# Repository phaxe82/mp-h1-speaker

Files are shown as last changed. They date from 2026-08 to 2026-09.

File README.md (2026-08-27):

# MP-H1 — a high-sensitivity 2-way with a 3D-printed tractrix horn

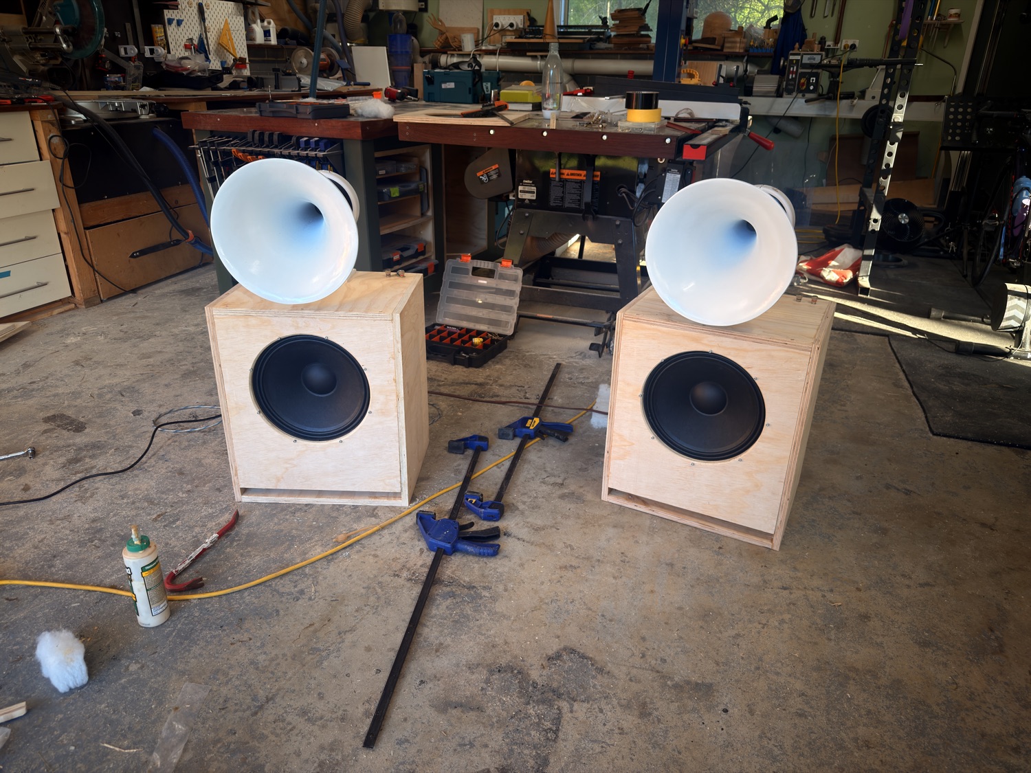
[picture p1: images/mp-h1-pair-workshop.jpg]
The MP-H1 pair, fresh off the bench


An OJAS / Devon Turnbull–inspired two-way: a 12″ pro woofer in a modest reflex
box, and a 1.4″ compression driver on a **3D-printed round tractrix horn** that
sits on top of the cabinet. Both drivers run from a **single amplifier channel**;
the passive crossover is four parts (on the compression driver only) and all the
voicing is done in DSP.

The point of this repo is that it's **designed from the Thiele/Small parameters
up** — the horn profile, the box alignment, and the drawings are all *generated*
by the scripts here. Change the driver, the box volume, or the flare cutoff, and
you can regenerate the whole design.

📄 **Start with the [full build & design paper (PDF)](speaker_docs/MP-H1-Build-and-Design.pdf)** — the maths, the crossover, the tuning method, and the story, in one place.

---

## Specs (as built)

| | |
|---|---|
| **Format** | Two-way, high-efficiency · passive XO (CD only) + DSP voicing · single amp channel |
| **Woofer** | 12″ Peerless by Tymphany **FSL-1225R02-08** — 96.2 dB, reflex |
| **Compression driver** | 1.4″ SB Audience **ROSSO-65CD-T** — 108 dB, titanium |
| **Enclosure** | 62 L net reflex, **f_b ≈ 47 Hz** · 456 × 536 × 366 mm · 18 mm Baltic birch · front slot port |
| **Horn** | Round tractrix, **f_c = 340 Hz** · Ø321 mm mouth · 303 mm long · printed in sections |
| **Crossover** | ≈ 1.2 kHz 2nd-order Butterworth (12 µF + 1.5 mH) · L-pad 6.8 Ω / 2.7 Ω |
| **Extension** | F3 = 67 Hz · F6 = 47 Hz · F10 = 38 Hz — flat into the mid-40s in-room with DSP |
| **Amplification** | Single channel — NAD C 700 + Dirac Live |
| **Cost** | ≈ AU$1,650–1,850 / pair |

## The design, in three ideas

- **Minimal passive parts.** The woofer runs *direct* — no series inductor. Only the compression driver carries a network (a 2nd-order high-pass + a level-matching L-pad).
- **Efficiency first.** 96 dB woofer, 108 dB horn — happy on a handful of watts, so amp quality matters more than power.
- **DSP does the voicing.** Baffle-step, the low-shelf lift, the 40 Hz excursion high-pass and room correction all live in DSP, not the crossover.

## What's in here

```
scripts/        The generators — the reproducible heart of the design
  tractrix.py     horn profile from a flare cutoff frequency
  horn_cad.py     builds the printable horn (neck + bell quadrants), headless build123d
  box_model.py    vented-box (Small) alignment + port model, per driver
  drawings.py     dimensioned cutting drawings (matplotlib → PDF)
cad/            STL (print), STEP (universal CAD), F3D (Fusion), 3MF, drawings.pdf, profile CSVs
speaker_docs/   design-notes.md · BOM.md · build-guide.md · dsp-tuning-guide.md · the build paper (PDF)
website/        the crossover schematic + board-layout page (open index.html)
images/         build photos
```

## Regenerate the design

```bash
python3 -m venv .venv
.venv/bin/pip install build123d numpy scipy matplotlib

.venv/bin/python scripts/box_model.py                     # box alignment + port, prints the response
.venv/bin/python scripts/tractrix.py 340 cad/horn_profile_340.csv   # horn profile CSV
.venv/bin/python scripts/horn_cad.py                      # → cad/horn_neck.stl + horn_bell_quadrant.stl (+ .step)
.venv/bin/python scripts/drawings.py                      # → cad/drawings.pdf
```

Want a different horn? Change the flare cutoff (`tractrix.py <fc>`); a different
woofer or box? Edit the T/S set / volume in `box_model.py` and re-check the
alignment before you cut anything.

## Print the horn

Per speaker: **1 × `horn_neck.stl` + 4 × `horn_bell_quadrant.stl` + 1 × `driver_stand.stl`**.

- **PETG**, 0.2 mm layers, **6 mm walls** (≈ 8 perimeters or 30 %+ gyroid). The horn must be *dead* — a knuckle-rap should give a dull thock, not a ring.
- The bell quadrants are one identical part rotated 90° four times, with **integral tongue-and-groove** on every seam — dry-fit, epoxy in the grooves, tape, cure. No hardware.
- The **driver stand is structural** (it carries the 3.76 kg driver) — 50 %+ infill, 6 perimeters.

Full sequence, finishing, and the wiring in **[speaker_docs/build-guide.md](speaker_docs/build-guide.md)**.

## Build & tune

1. Order parts — **[speaker_docs/BOM.md](speaker_docs/BOM.md)**
2. Start the horn prints (longest lead time)
3. Build the cabinets — **[speaker_docs/build-guide.md](speaker_docs/build-guide.md)** + the drawings in `cad/`
4. Wire the crossover (**[website/index.html](website/index.html)** has the schematic + board layout), assemble, then measure and voice — **[speaker_docs/dsp-tuning-guide.md](speaker_docs/dsp-tuning-guide.md)**

> **One hard-won tip:** before you second-guess the acoustics on first power-up, **battery-test your woofer polarity**. A single reversed woofer makes a stereo pair sound thin and lifeless — the two cancel in the room. Ask me how I know.

## Licence

- **Hardware, CAD, and docs** → [CC BY-SA 4.0](LICENSE) (share & adapt, keep derivatives open, credit the source)
- **Scripts** (`scripts/`) → [MIT](LICENSE-CODE)

Build it, remix it, improve it — please do. If you make a better horn, open a PR.

---

*Designed and built by Tom Andrews on the Mornington Peninsula, Australia.
Round tractrix, single-amp, high-sensitivity two-way. Next revision: **MP-H2**,
an elliptical R-OSSE waveguide swap-in.*

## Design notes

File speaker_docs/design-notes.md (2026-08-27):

# Design Notes — MP-H1 (OJAS-Style 2-Way Horn Speaker)

**MP-H1** — Mornington Peninsula, Horn, rev 1: round-tractrix, single-amp,
high-sensitivity 2-way. (MP-H2 reserved for the elliptical R-OSSE waveguide swap.)

All the acoustic math behind the build, with sources. Scripts that produced
these numbers: `scripts/box_model.py`, `scripts/tractrix.py`.

## 1. Concept

Two-way, high-efficiency: 12" reflex bass bin + compression driver on a
3D-printed round tractrix horn sitting on top. Modeled on the OJAS (Devon
Turnbull) two-way — the real kit uses a FaitalPRO 15PR400 + HF10AK on a long
tractrix; the Klipsch×OJAS kO-R2 crosses at 760 Hz with 97 dB sensitivity.
Drivers here are Celestion for Australian availability.

Amplification: 2-channel amp with DSP. So: **woofer runs direct** (no series
parts), **compression driver gets a passive 2nd-order high-pass + L-pad**,
and all voicing is DSP PEQ. This mirrors OJAS practice (minimal passive
parts, high-efficiency drivers, low amplifier power).

## 2. Drivers (datasheet values)

> **Revision 2 (July 2026):** design re-based on Wagner Online stock —
> Celestion proved unobtainable in Australia (TF1225 out of stock at the
> stockists checked; CDX14-3050 $499 at the one that had it). Both
> replacement drivers below are stocked by
> [Wagner Online](https://www.wagneronline.com.au) (Australian
> SB Audience / Peerless / Dayton distributor). Original Celestion figures
> remain in `box_model.py` for reference.

### Woofer — Peerless by Tymphany FSL-1225R02-08 (8 Ω), chosen
| Fs | Qts | Qes | Vas | Re | BL | Sd | Xmax | Mms | Le | Sens | Power |
|---|---|---|---|---|---|---|---|---|---|---|---|
| 63.0 Hz | 0.44 | 0.49 | 54.8 L | 5.5 Ω | 14.9 Tm | 547 cm² | 5.3 mm | 50.1 g | 0.54 mH | 96.2 dB | 233 W AES |

Pro-style pressed-steel 12", paper cone, 65 mm voice coil, spec'd by
Tymphany as "extremely flat response up to 3,000 Hz" — the same recipe as
the TF1225 it replaces, with more Xmax. Frame Ø313.5 mm, depth ~96 mm
(shallower than the TF1225's 130 mm — more brace clearance). **Baffle
cut-out: nominal Ø285 mm — verify against the delivered driver before
routing** (the cutout/bolt-PCD page of the datasheet isn't in any public
mirror; 12" pro frames land 283–287 mm).

*(Earlier candidates: Celestion TF1225 — unobtainable in AU;
FTR12-3070C — rejected, higher Fs / smaller Vas = less extension.)*

### Compression driver — SB Audience ROSSO-65CD-T (8 Ω)
- **108 dB** 1W/1m, 70 W AES (140 W max), RDC 6.2 Ω
- Frequency range 500–20,000 Hz; **recommended crossover 1 kHz**
- Throat exit **35.6 mm (1.4")**, fitting **4 × M6 at 90° on Ø102 mm PCD** —
  identical to the Celestion CDX14-3050 it replaces, so **the printed horn
  flange in `cad/` fits unchanged** (36.0 mm bore vs 35.6 mm exit is a
  0.2 mm/side step; give the throat entry a light chamfer when finishing)
- 65 mm titanium diaphragm, ferrite motor, annular phase plug, copper-cap
  demodulation, 18.4° conical exit angle
- Body **Ø156 mm, depth 65.9 mm, 3.76 kg** — bigger and heavier than the
  Celestion (Ø125 mm / 1.7 kg): driver stand resized accordingly
  (Ø157 mm clamp ring, 50×50 column, 110×110×10 base)

## 3. Bass bin alignment (box_model.py)

Model: Small's 4th-order vented transfer function, QL = 7. Code sanity-checked
against the textbook B4 alignment (reproduces −3.01 dB at f0 with
Qts = 0.383, α = 1.414).

**Chosen: Vb = 62 L net (the as-modeled cabinet), fb = 48 Hz**
(FSL-1225R02-08: α = 0.88, h = 0.76). The cabinet was designed around the
TF1225 at the same tuning, and the FSL-1225 lands in the same place — with
the unchanged 150 mm duct the actual tuning computes to ~47 Hz. **No cabinet
or port change was needed for the driver swap.**

| f (Hz) | 40 | 45 | 50 | 55 | 60 | 70 | 80 | 100 | 150 | 200 |
|---|---|---|---|---|---|---|---|---|---|---|
| dB | −9.0 | −6.7 | −5.3 | −4.4 | −3.7 | −2.7 | −2.0 | −1.2 | −0.4 | −0.2 |

F3 = 67 Hz, F6 = 47 Hz, F10 = 38 Hz — essentially identical extension to the
original Celestion alignment. The rolloff is intentionally shallow (QB3-ish
pro-driver alignment): a gentle DSP low-shelf (+3–4 dB below ~100 Hz) plus
normal room gain gives flat in-room response into the mid-40s.

**Excursion:** ~2.5 mm peak at 30 W across 48–200 Hz vs Xmax 5.3 mm — fine.
Below fb the cone unloads, so **set a DSP high-pass at 40 Hz (24 dB/oct)**,
especially if using the low-shelf boost.

**Port:** full-width slot at the bottom of the front baffle (as in the
reference photo), formed by a shelf above the cabinet floor:
- Slot: **420 mm wide × 28 mm high** (Sp = 117.6 cm²)
- Physical duct length (front-to-back): **150 mm** (end correction 0.85·d_eq)
- Port velocity at fb, 30 W: ≈ 16.5 m/s peak — under the ~17 m/s chuffing
  threshold at realistically loud levels (30 W on 97 dB = ~112 dB peaks).

**Cabinet internal:** 420 W × 500 H × 330 D mm = 69.3 L gross.
Deductions: driver ≈ 3 L, port duct air 1.8 L, port shelf wood 1.1 L,
bracing ≈ 1 L → **net ≈ 62 L** (within 5% of target; tuning shifts <1 Hz).
External with 18 mm Baltic birch: **456 W × 536 H × 366 D mm**
(H/W = 1.18, matching the photo's proportions).

## 4. Horn (tractrix.py)

Tractrix with mouth radius r_m = c/(2π·fc); profile closed form
x(r) = r_m·ln((r_m + √(r_m²−r²))/r) − √(r_m²−r²).

**Chosen: fc = 340 Hz** → mouth **Ø321 mm**, axial length **303 mm** from
36 mm throat. Loading is effective from ~450 Hz, i.e. > 1.5 octaves below
the 1.15 kHz crossover — generous margin. (fc = 400 Hz / Ø273 was computed
as the smaller alternative; 340 Hz matches the photo scale and loads lower.)
Profile CSV for CAD: `cad/horn_profile_340.csv`.

**Print sectioning (235 × 235 × 250 mm bed) — as modeled in `cad/`:**
- **Neck** (throat → split at x = 230 mm): one vertical piece,
  167.5 × 167.5 × 238 mm, integrated CDX14/ROSSO bolt flange (Ø130 × 8 mm,
  4 × M6 on Ø102 PCD, Ø6.5 clearance holes).
- **Bell** (x 230–303 mm): 4 identical quadrants, 168.6 × 166.6 × 72.6 mm each.
- Wall 6 mm throughout.

> **Rev 3 (Aug 2026): screwless joints.** The rev-2 print run showed the bell
> quadrants fitting poorly — the only registration feature was 8 × Ø4×20mm
> pin sockets across the *neck-to-bell* split; the four quadrant-to-quadrant
> seams (where the visible misalignment actually was) had no registration at
> all, just a butt joint held square by hand while the epoxy set. Replaced
> the pins with **integral tongue-and-groove joints printed directly into
> the parts, on every split**: a continuous ring at the neck-bell interface,
> plus 3 tabs per quadrant-to-quadrant seam (tongue on one radial face,
> groove on the other — all 4 quadrants stay a single identical STL, since
> a part with tongue on its "trailing" face and groove on its "leading"
> face self-tiles into a ring under 90° rotation). No hardware, no drilling;
> assembly is dry-fit → epoxy in the grooves → tape/clamp → cure. Joint
> clearance is 0.15mm/side (width) and 0.2mm (depth) — tune in
> `scripts/horn_cad.py` (`GROOVE_CLEAR_W`/`GROOVE_CLEAR_D`) if your printer
> runs tighter or looser than that.
>
> **`scripts/horn_cad.py` (build123d, headless) is now the source of truth
> for `cad/horn_neck.stl` and `cad/horn_bell_quadrant.stl`** — regenerate
> with `.venv/bin/python scripts/horn_cad.py` after any profile/joint
> change. `speaker-full-design.f3d` still owns the cabinet and driver
> stand; it was not updated for this revision and is stale for the horn
> specifically.

## 5. Crossover / electrical

Both drivers hang on one amp channel. Woofer direct. CD chain:
**2nd-order Butterworth high-pass → L-pad → driver.**

- Target corner ≈ **1.2 kHz** acoustic (ROSSO recommended min is 1.0 kHz; the
  horn's own rolloff below ~450 Hz adds protection).
- Into 8 Ω: **C = 12 µF** (series, film/MKP 250 V) and **L = 1.5 mH**
  (shunt, air core, ≥0.7 mm wire). fc = 1/(2π√(LC)) = 1.19 kHz, Q ≈ 0.72. ✓
- **L-pad −12 dB** (ROSSO 108 → woofer 96.2 dB): series **6.2 Ω**, shunt
  **2.7 Ω** (10 W wirewound each; gives −12.2 dB into ~8.2 Ω). Keeps ~8 Ω
  load and damps horn impedance peaks. Alternates: −10.5 dB = 5.6 Ω/3.3 Ω;
  −13.5 dB = 6.8 Ω/2.2 Ω. Final trim by ear / REW after measuring actual
  sensitivity on *this* horn (spec sensitivity is on SB's H280 horn, ±~2 dB
  on ours).
- System impedance minimum ≈ 4.4 Ω near crossover (woofer ~9.6 Ω at 1.5 kHz
  in parallel with padded network) — safe for any 4 Ω-rated amp channel.
- DSP does the rest: 40 Hz HP, low-shelf, baffle-step/room EQ, and any
  top-octave lift (above ~5 kHz global EQ only affects the horn anyway).

## 6. References

- SB Audience ROSSO-65CD-T spec + dimension sheets (sbaudience.com)
- Peerless FSL-1225R02-08 T/S set (loudspeakerdatabase.com; Tymphany product page)
- Celestion TF1225 / CDX14-3050 / FTR12-3070C datasheets (rev-1 design, for reference)
- Small, R. "Vented-Box Loudspeaker Systems" JAES 1973 (transfer function)
- Klipsch × OJAS kO-R2 product page (reference: 760 Hz crossover, 97 dB)
- OJAS 2-way DIY kit (FaitalPRO 15PR400 + HF10AK, long tractrix)

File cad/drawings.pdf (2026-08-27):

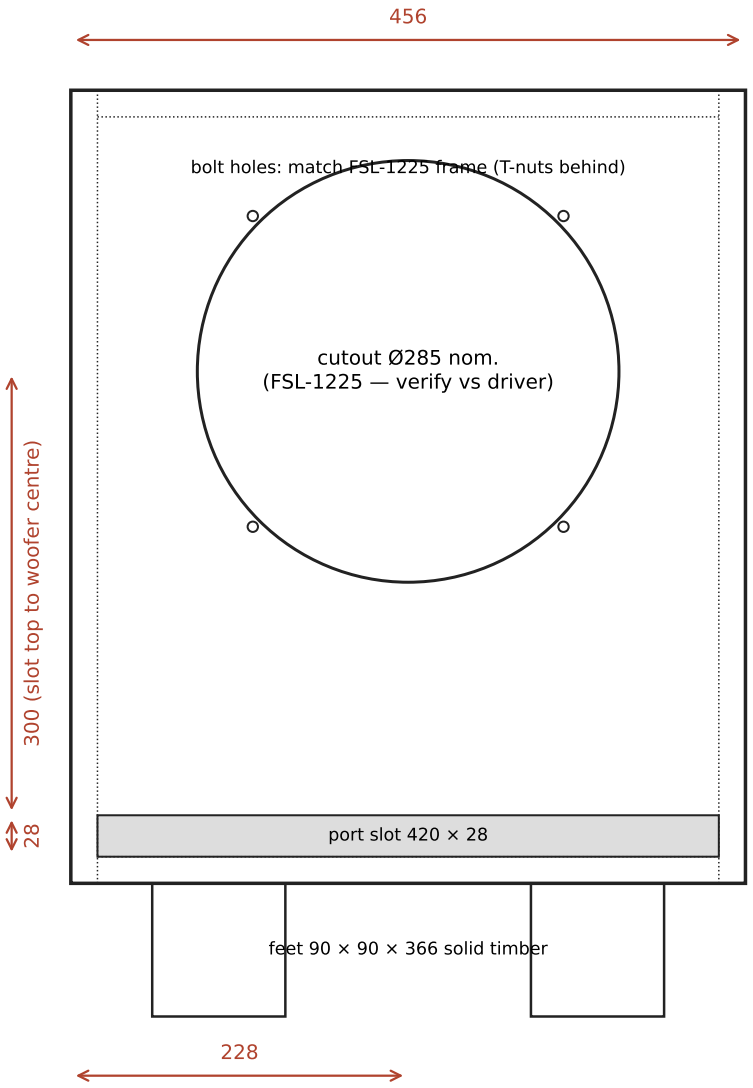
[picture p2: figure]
port slot 420 × 28; cutout Ø285 nom. (FSL-1225 — verify vs driver); feet 90 × 90 × 366 solid timber; 28 300 (slot top to woofer centre)

bolt holes: match FSL-1225 frame (T-nuts behind)

536

## Sheet 1 — Cabinet front elevation (mm)

port shelf

window brace 420×330, 300×210 cutout

duct 150 deep × 28 high

FSL-1225
depth ~96

terminal Ø60 @ z=100

CD cable exit Ø10 @ y=183

366

536

28 duct

132 shelf

## Sheet 2 — Vertical section, side view (mm)

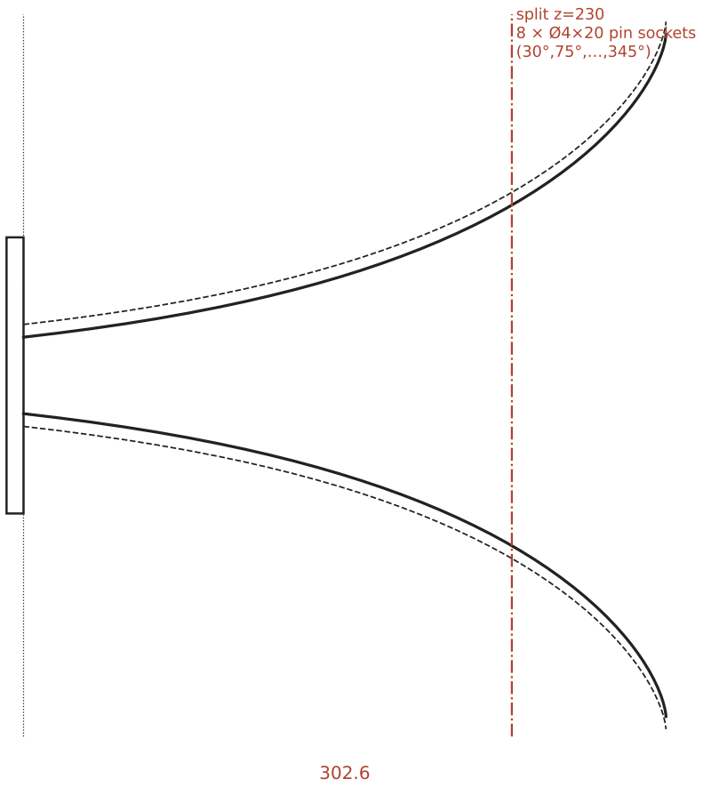
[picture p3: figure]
split z=230 8 × Ø4×20 pin sockets (30°,75°,…,345°)

flange Ø130×8
4×M6 on Ø102 PCD
(ROSSO-65CD-T)

Ø321 mouth
Ø36 throat

wall 6 mm · neck prints vertical (174×174×238) · bell = 4 identical quadrants (161×161×73)

## Sheet 3 — Horn section, tractrix fc = 340 Hz (mm)

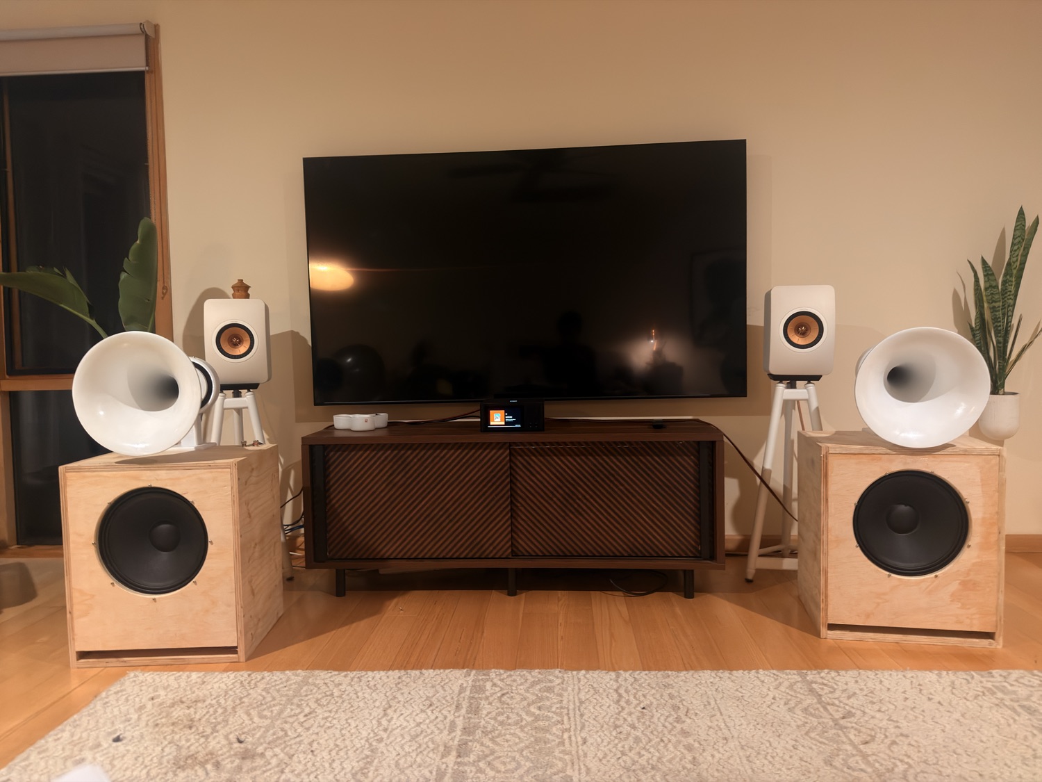
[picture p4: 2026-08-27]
images/mp-h1-pair-inroom.jpg

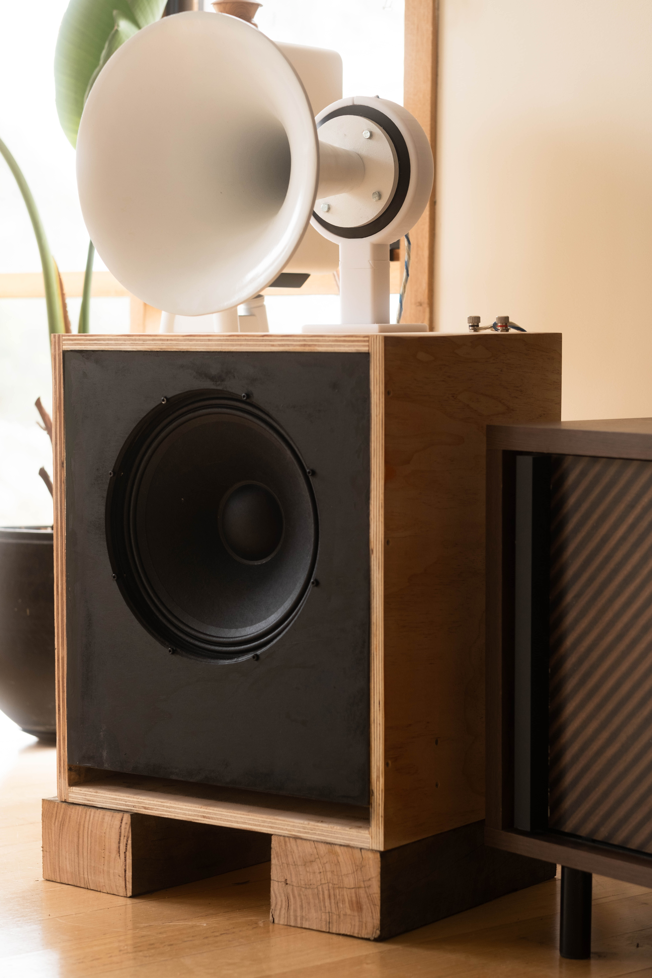
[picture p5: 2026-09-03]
images/untitled-89.jpg

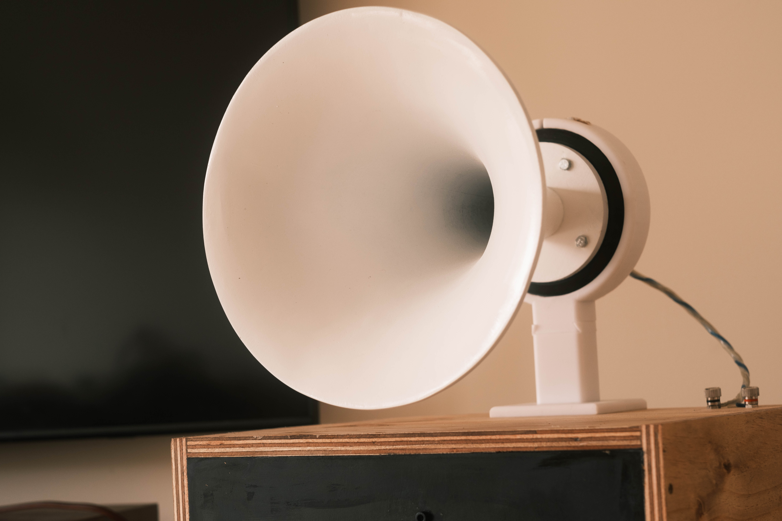
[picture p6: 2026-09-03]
images/untitled-86.jpg

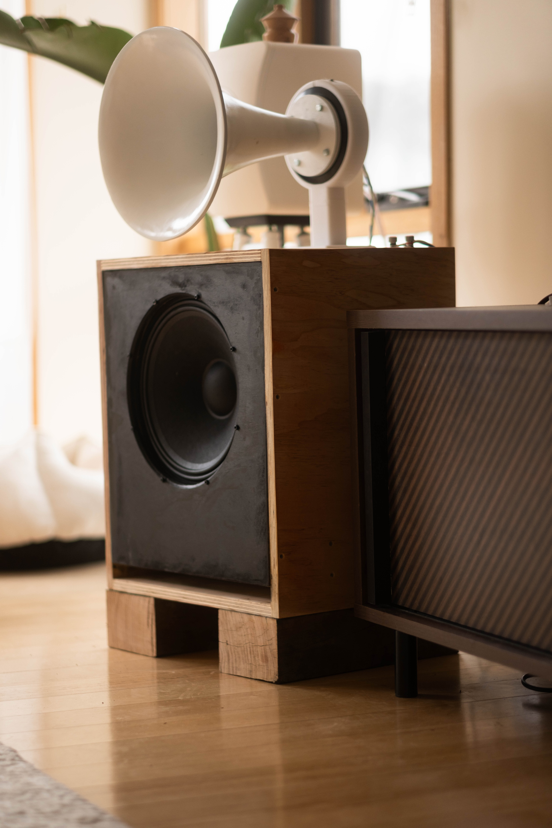
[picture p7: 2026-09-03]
images/untitled-114.jpg

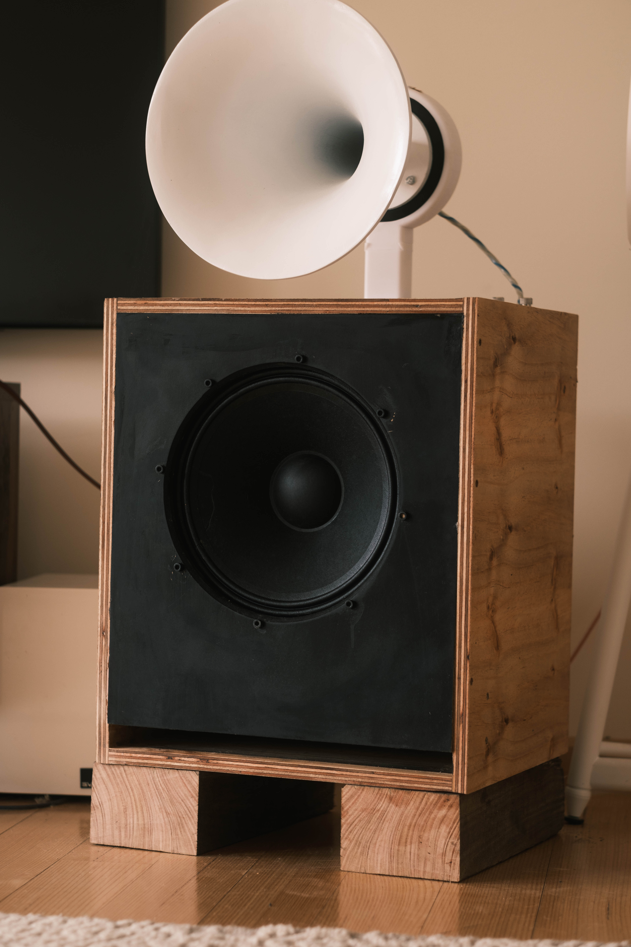
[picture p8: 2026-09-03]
images/untitled-95.jpg

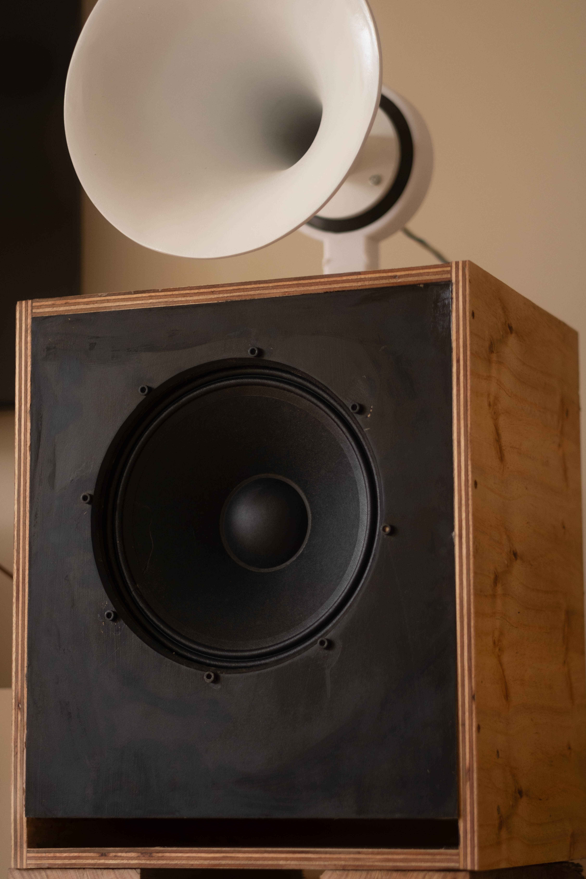
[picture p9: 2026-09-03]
images/untitled-107.jpg

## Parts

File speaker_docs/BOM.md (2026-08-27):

# Bill of Materials — MP-H1 (OJAS-Style 2-Way, pair)

Prices checked July 2026; confirm stock at order time — small-run pro-audio
stock moves fast.

## Drivers — Wagner Online (rev 2, July 2026)

Both confirmed listed at [Wagner Online](https://www.wagneronline.com.au)
(Sydney; AU distributor for SB Audience / Peerless / Dayton). Wagner's site
blocks price scraping — check the product page or call (02) 9798 9233 for
current pricing; estimates below are from US street prices + typical AU markup.

| Qty | Item | Source | Est. AUD | Stock (checked) |
|---|---|---|---|---|
| 2 | Peerless by Tymphany FSL-1225R02-08 12" pro woofer, 8 Ω | [Wagner product page](https://www.wagneronline.com.au/product/peerless-by-tymphany-12-woofer-driver-994241?sku=fsl-1225) | ~$150–190 ea (US$74 at DigiKey) | Listed; Parts-Express has it on clearance — if Wagner is out, order 2 spares-worth while it lasts |
| 2 | SB Audience ROSSO-65CD-T 1.4" compression driver, 8 Ω | [Wagner product page](https://www.wagneronline.com.au/product/sb-audience-1-4-compression-driver-1005231?sku=rosso-65cd-t) | ~$260–320 ea (US$156 at Madisound) | **In stock** per Wagner listing |

Driver subtotal ≈ **$850–1,000** — back inside the original budget tier.

**Superseded (rev 1):** Celestion TF1225 + CDX14-3050 — TF1225 out of stock
at every AU stockist checked; CDX14-3050 $499 ea at the single stockist
(Crossfader). The Celestion pair remains a valid drop-in if stock returns:
same cabinet, same horn flange; use the rev-1 L-pad values in git history.

## Crossover (per speaker: C + L + 2 resistors)

| Qty | Item | Notes | Est. AUD |
|---|---|---|---|
| 2 | 12 µF MKP film capacitor, ≥400 V | **as built: PB-MKP-FC 12 µF 400 V**. Jantzen Cross-Cap / Dayton PMPC also fine (≥250 V); 10 µF + 2.2 µF parallel works too | ~$15 ea |
| 2 | 1.5 mH air-core inductor, ≥0.9 mm (20 AWG) wire | Jantzen air core; DCR ≤0.6 Ω | ~$25 ea |
| 2 | 6.8 Ω 10 W wirewound resistor | **L-pad series, as built** (6.8 Ω = −12.8 dB; 6.2 Ω nominal was −12.2 dB). Buy 5.6 Ω and 8.2 Ω too for ±1.5 dB trim (cheap) — see below | ~$4 ea |
| 2 | 2.7 Ω 5 W wirewound resistor | **L-pad shunt, as built** (5 W is fine — the shunt leg dissipates ~¼ of the series leg; 3.3 Ω / 2.2 Ω alternates) | ~$3 ea |

Mount parts on a small ply board on the cabinet floor. Subtotal ≈ **$100**

## Timber & cabinet hardware

| Qty | Item | Notes | Est. AUD |
|---|---|---|---|
| 2 sheets | 18 mm Baltic birch plywood, 2400×1200 | ~1.3 sheets needed; spare covers mistakes. AA/BB grade for exposed edges | ~$140 ea |
| 1 | Solid timber for feet, ~90×90 mm section, 1.6 m (e.g. Vic ash / oak) | 4 blocks per photo style | ~$60 |
| 8 | Binding posts (4 per speaker) | rear pair = amp input, top pair = external-horn feed through the lid (bed in sealant) | ~$4 ea |
| 4 | Wago 221 lever-nuts | join the negative rail (amp / woofer / crossover-in) — 2 per speaker | ~$2 ea |
| 8 | M6 T-nuts + M6×35 hex bolts (woofer) | 4 per woofer | ~$15 |
| 8 | M6×25 bolts + washers (CD to horn flange) | 4 per driver | ~$8 |
| 2 m² | Polyester/wool acoustic wadding | line rear + side walls | ~$25 |
| — | Foam gasket tape, wood glue, screws | | ~$25 |
| 4 m | Internal cable 1.5 mm² + spade terminals for CD | | ~$15 |

Subtotal ≈ **$440**

## Horn & finish

| Qty | Item | Notes | Est. AUD |
|---|---|---|---|
| ~5 kg | PETG or PLA+ filament | ~2–2.5 kg per horn incl. supports/stand; PETG preferred (sanding + heat resistance) | ~$150 |
| 2 | M5 × 30 bolt + nyloc nut (stand clamp) + 8 × 4 mm wood screws (stand base) | stand is fully printed | ~$8 |
| — | 4 mm rod or filament offcuts for horn joint pins (16 × 20 mm pins) | | ~$0 |
| — | Body filler / spot putty, sandpaper 120–600 | seam finishing | ~$40 |
| — | High-build primer + white satin/gloss acrylic spray | the seamless white look | ~$50 |

Subtotal ≈ **$255**

## Measurement (if not already owned)

| Qty | Item | Notes | Est. AUD |
|---|---|---|---|
| 1 | miniDSP UMIK-1 USB measurement mic | for REW; used for DSP tuning | ~$150 |

## Total ≈ **$1,650–1,850** for the pair (excl. mic)

Rev-2 drivers (~$850–1,000 via Wagner) bring the build back inside the
original ~$800–1000 driver tier. Wagner also stocks the crossover parts
(Jantzen/Dayton caps & coils, resistors) and speaker terminals — most of
this BOM can ship in one box; plywood and timber are the only local buys.

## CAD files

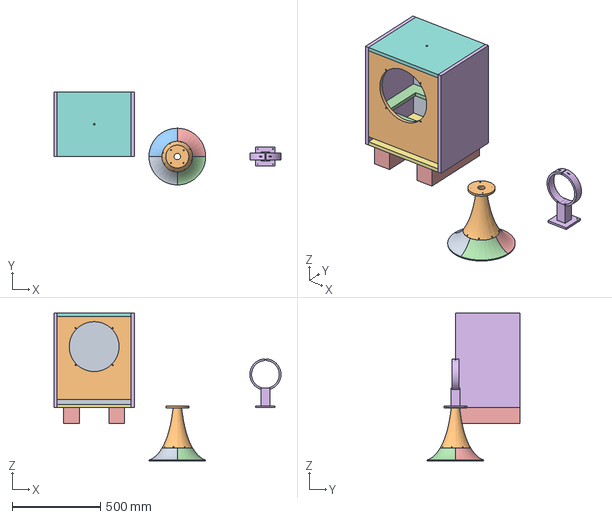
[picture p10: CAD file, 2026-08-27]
cad/speaker-full-design.step
1288.4 x 527.0 x 838.6 mm

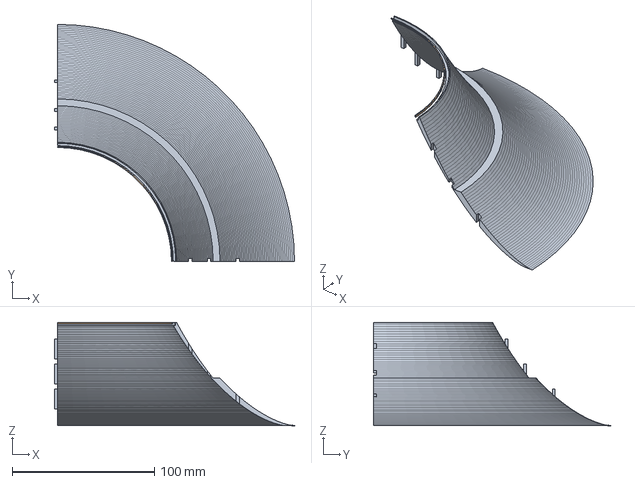
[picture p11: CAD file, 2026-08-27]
cad/horn_bell_quadrant.step
168.6 x 166.6 x 72.6 mm

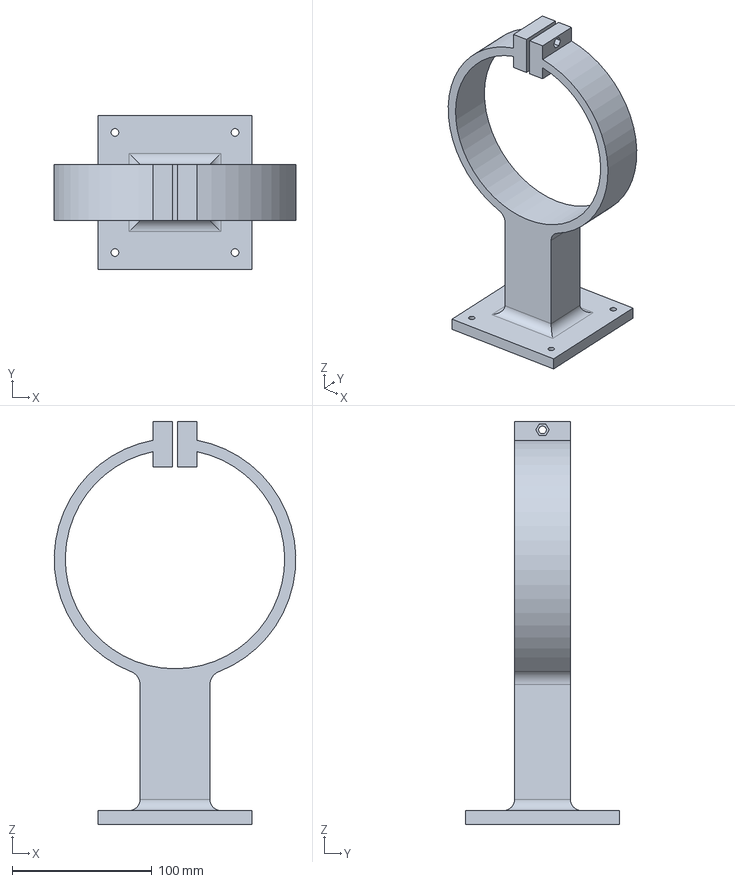
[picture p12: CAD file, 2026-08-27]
cad/driver_stand.step
172.9 x 110.0 x 288.5 mm

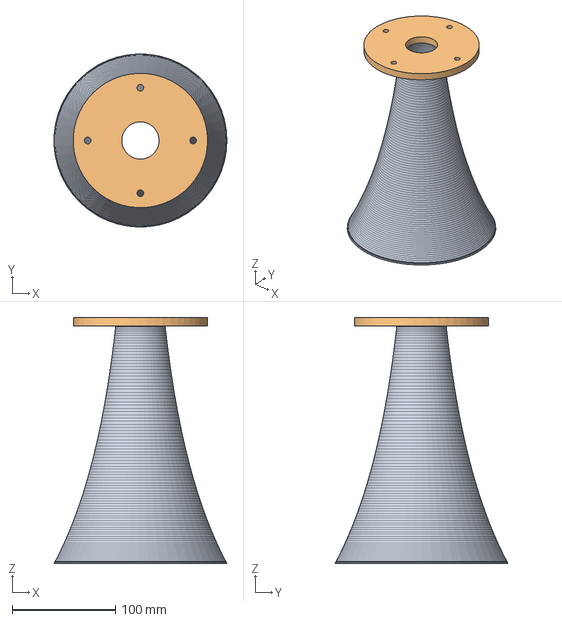
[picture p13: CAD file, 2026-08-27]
cad/horn_neck.step
167.3 x 167.4 x 238.0 mm

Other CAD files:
cad/driver_stand.stl
cad/horn_bell_quadrant.3mf
cad/horn_bell_quadrant.stl
cad/horn_neck.3mf
cad/horn_neck.stl
cad/speaker-full-design.f3d

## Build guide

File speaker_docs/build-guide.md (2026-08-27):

# Build Guide — OJAS-Style 2-Way

Read `design-notes.md` first for the why; this is the how. Dimensioned
drawings and cut list live in `cad/`.

## 1. Cabinet (per speaker) — 18 mm Baltic birch

External 456 W × 536 H × 366 D mm. Butt joints, glued and screwed (screws
hidden on bottom/back or plugged); the photo look leaves ply edges exposed
on the sides, with the front baffle set flush between them.

### Cut list (per cabinet, 18 mm ply)
| Panel | Size (mm) | Qty | Notes |
|---|---|---|---|
| Sides | 536 × 366 | 2 | edges exposed front + top |
| Top / Bottom | 420 × 366 | 2 | fit between sides |
| Back | 420 × 500 | 1 | fits between sides, top, bottom |
| Front baffle | 420 × 472 | 1 | stops 28 mm above the bottom panel → the port slot |
| Port shelf | 420 × 132 | 1 | butts against baffle rear, 28 mm above bottom; with the baffle it forms the 150 mm duct |
| Window brace | 420 × 330 (cut ~60% out) | 1 | mid-height, ties sides/back |
| Crossover board | ~150 × 200 | 1 | screwed to floor after wiring |

*(Exact sizes and the woofer cutout position come from the CAD drawings —
`cad/` is authoritative if anything differs.)*

### Assembly order
1. Cut all panels; cut the woofer hole (nominal Ø285 mm for the FSL-1225 —
   **verify against the delivered driver**) in the baffle with a router
   trammel. Woofer centre is on the vertical centreline, 300 mm up from the
   baffle's bottom edge (i.e. above mid-height, per the photo).
2. Mark the woofer mounting holes from the driver frame itself and fit M6
   T-nuts from the rear.
3. Glue the port shelf between the sides, 28 mm above the bottom panel
   (rest it on temporary 28 mm spacer offcuts during glue-up) — the duct is
   open at the front (the slot) and opens into the box at the back, 150 mm
   deep in total (18 mm baffle + 132 mm shelf), full 420 mm width.
4. Box glue-up: bottom + sides + top around the back panel, then the window
   brace at mid-height (glued to sides and back, clear of the woofer magnet
   by ≥20 mm — check interference drawing).
5. Fit the baffle flush. Seal every internal seam with a glue fillet.
6. Binding posts: back pair low on the back (amp input), top pair through the
   top panel (horn feed) — bed both top posts in sealant. Wire to the crossover
   board before mounting drivers.
7. Wadding on back and side walls (not in the port path, not stuffed).
8. Crossover board on the floor; woofer wired direct off the back posts, CD
   high-pass/L-pad output run up to the sealed top posts (see §3).
9. Gasket tape on the woofer frame; bolt in the woofer.
10. Feet: two solid blocks ~90 × 90 × 366 mm under the cabinet, set in from
    the sides as in the photo (glued dowels or screwed from inside).

### Finish
Sand to 180, exposed ply left natural (hardwax oil or matte poly). Baffle
painted light warm grey (as in the photo) before final assembly if you want
the crisp two-tone look.

## 2. Horn — 3D print (per speaker)

Parts (STLs in `cad/`): 1 neck (with CDX14 flange), 4 bell quadrants,
driver stand parts.

**Print settings:** PETG, 0.2 mm layers, 6 mm walls printed as ~8 perimeters
or 30%+ gyroid with 3 mm shells — the horn must be *dead* (knuckle-rap test:
a dull thock, not a ring). Neck prints vertically, flange down, no supports
except under the flange bolt bosses. Quadrants print bell-face up with
tree supports on the outer flare.

**Assembly:**
1. Bolt-check the neck flange against the ROSSO-65CD-T (4 × M6 on Ø102 PCD)
   before gluing anything.
2. Glue quadrants to each other and to the neck with 2-part epoxy. The
   neck↔bell joint face has 8 × Ø4 × 10 mm deep pin sockets (at 30°, 75°,
   120° … 345°) — cut 20 mm pins from 4 mm rod/filament to register the
   parts. Dry-fit the whole bell first, then epoxy, pin, and tape/strap
   until cured. Run an epoxy fillet around the outside of every seam
   (it disappears under filler).
3. Fill seams (spot putty), sand 120 → 400, high-build primer, sand 600,
   white satin/gloss topcoats. Inside of the bell matters visually;
   inside of the *neck* matters acoustically — keep it smooth.
4. Mount the CD to the neck flange with a thin gasket (supplied with driver
   or cut from 1 mm foam).

**Stand:** the CD + horn (~5 kg total: ~1.3 kg print + 3.76 kg ROSSO driver)
hangs from the printed stand (`cad/driver_stand.stl`): a Ø157 mm clamp ring
that grips the driver body, closed with an M5 × 30 bolt + nyloc across the
top slot, on a 50 × 50 column and 110 × 110 × 10 base screwed to the cabinet
top with 4 × 4 mm wood screws. Ring centre is 188 mm above the cabinet top,
which floats the bell ~20 mm clear of the lid as in the photo. Print it
lying on its side (177 × 110 × 277 mm — fits a 235 mm bed on the diagonal),
50%+ infill and 6 perimeters — it carries 5 kg, it's structural.

## 3. Electrical

**Terminals: 4 binding posts per speaker** (not a terminal cup). The horn is
external on top, so its feed exits the box:
- **Back pair** = amp input.
- **Top pair** = the CD high-pass + L-pad *output*, up through the top panel
  to the horn via twisted flex. Bed both top posts in sealant (they pierce
  the ported box near ear height).

Signal path (one amp channel):
```
Amp ──► BACK posts ──┬──► Woofer            (direct, no parts)
                     │
                     └──► 12µF series ──●A──► 6.8Ω series ──●B──► TOP posts ──► Horn
                                        │                  │
                                     1.5mH              2.7Ω
                                        │                  │
          negative rail ───────────────┴──────────────────┴─── (all shunt returns + horn − + amp − + woofer −)
```
- **Woofer taps directly off the back posts**, in parallel with the crossover
  input — it must not run through any crossover part.
- Join the negative rail with **two Wago 221 lever-nuts** (one for +, one for
  −): amp / woofer / crossover-in all land together. Anchor the Wagos so they
  don't rattle.
- **L-pad is as-built 6.8 Ω series / 2.7 Ω shunt** (≈ −12.8 dB; nominal spec
  was 6.2 Ω / 2.7 Ω = −12.2 dB — the horn lands ~0.6 dB quieter, recovered in
  DSP). Leave the L-pad resistor leads long / on a Wago so they're swappable —
  you re-trim by ear/REW once you measure *this* horn (see below).
- **Polarity: start with the CD inverted** (common for a 2nd-order HP at these
  spacings); confirm by measuring the crossover null/sum in REW. Mark the top
  posts' +/− clearly so you can flip deliberately.

### L-pad trim (do this during voicing, not the build)
Full procedure is `dsp-tuning-guide.md` step 3 (level-match). In short:
1. Measure horn-band vs woofer-band level at 1 m (pink noise, 2–8 kHz vs
   200–800 Hz).
2. If the horn is **>±1.5 dB** off, change the **series** resistor rather than
   burning DSP headroom: **larger = quieter horn** (6.8 → 8.2 Ω), **smaller =
   louder** (6.8 → 6.2 → 5.6 Ω). Leave the 2.7 Ω shunt unless you need a big
   swing.
3. Re-confirm polarity/sum after any resistor change, then hand the last dB
   to DSP.

Then follow `dsp-tuning-guide.md`.

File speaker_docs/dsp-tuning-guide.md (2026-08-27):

# DSP Tuning Guide

Goal: take the finished speakers from "assembled" to "voiced" using a
measurement mic and your amp's DSP. Budget an afternoon.

## Kit
- **miniDSP UMIK-1** USB mic (calibrated) — or any calibrated measurement mic
- **REW (Room EQ Wizard)** — free, macOS
- Mic stand, tape measure

## Baseline settings (before measuring)

Enter these first — they're from the design math, not taste:

| DSP block | Setting | Why |
|---|---|---|
| High-pass | 40 Hz, 24 dB/oct (Butterworth) | protects the woofer below fb = 48 Hz where the vented box unloads the cone |
| Low-shelf | +3 dB below 100 Hz, Q 0.7 | compensates the shallow QB3-style rolloff (design F6 = 47 Hz) |
| Peak EQ | −2 dB at 1.6 kHz, Q 2 (placeholder) | typical woofer/horn overlap bump; refine by measurement |

## Measurement session

1. **Nearfield sanity check** (mic 10 cm from woofer cone, then port):
   confirm the port output peaks around 48 Hz — that verifies box tuning.
   If it's off by more than ~3 Hz, adjust port depth (each −10 mm of duct
   raises fb ~1 Hz) before any EQ.
2. **Crossover polarity check**: measure at 1 m on the horn axis. Flip CD
   polarity (swap leads at the driver) and keep whichever gives a smooth
   sum through 1–1.5 kHz; the wrong one shows a deep suckout.
3. **Level match**: play pink noise band-limited 2–8 kHz vs 200–800 Hz.
   The horn band should sit level with the woofer band. If it's >±1.5 dB
   off, change the L-pad series resistor rather than burning DSP headroom.
   As-built is **6.8 Ω**: smaller = hotter horn (6.2 → 5.6 Ω), larger =
   quieter (8.2 Ω). Leave the 2.7 Ω shunt unless you need a big swing.
4. **Listening-position sweep** (mic at ear height, main seat, 3–5 spatially
   averaged positions): let REW's EQ tool generate corrections **below
   500 Hz only** (room modes). Above 500 Hz, correct only broad trends
   (Q ≤ 2, cuts preferred), never narrow dips.
5. **House curve**: aim for flat 200 Hz–2 kHz, then a gentle downward tilt,
   roughly −4 dB by 10 kHz at the listening position. Horns sound right
   with a slight top-octave shelf-down; trust your ears for the last dB.

## Notes specific to this design

- Both drivers share one amp channel, so every PEQ is global. That's fine:
  below 1 kHz only the woofer radiates, above ~5 kHz only the horn does —
  the overlap region 1–3 kHz is where to be gentle.
- The 12 µF/1.5 mH/L-pad network was designed for ~1.2 kHz into a nominal
  8 Ω horn load. If REW shows the acoustic crossover sitting far from
  1.2 kHz, adjust in DSP (shelf filters around the overlap), not by
  swapping passive parts, unless the error exceeds ~1/3 octave.
- Save the final DSP preset and export the REW session; keep both in
  `docs/measurements/` for the day you move rooms or rebuild something.

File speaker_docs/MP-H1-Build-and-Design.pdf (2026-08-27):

L O U D S P E A K E R · O P E N B U IL D & D E S I G N N O T E S | R E V 2 · A U G U S T 2026

# MP‑H1

## A high-sensitivity two-way with a 3D-printed tractrix

horn.

An OJAS-inspired two-way: a 12″ reflex bass bin and a 1.4″ compression driver on a printed round tractrix horn. Minimal passive parts, highefficiency drivers, and a single amplifier channel with DSP doing the voicing. Everything here — the acoustic maths, the crossover, the print files, the tuning method — is shared so you can build, adapt, or improve on it.

The finished pair — 12″ reflex bins and printed tractrix horns, fresh off the bench.

F O R M AT
Two-way, high‑efficiency
passive XO + DSP voicing

W O O FE R
12″ Peerless FSL‑1225

### 96.2 dB · reflex

H O R N / C D
1.4″ SB Audience ROSSO
108 dB · titanium

E N C L O S U R E

### 62 L reflex · fb ≈ 47 Hz

F6 = 47 Hz

C R O SS O VE R
≈ 1.2 kHz · 2nd‑order
on the CD only

A M PL I F I C AT I O N
Single channel + DSP
NAD C 700 · Dirac Live

By Tom Andrews — Mornington Peninsula, Australia · designed from the T/S parameters up. SHARE & REMIX FREELY

01 | The idea | CONCEPT & PHILOSOPHY

A modern take on the OJAS / Devon Turnbull two-way: horn-loaded efficiency and effortless dynamics, but designed around drivers you can actually buy and voiced with DSP instead of a wall of passive components.
The MP-H1 pairs a 12″ pro woofer in a modest reflex box with a 1.4″ compression driver on a 3D-printed round tractrix horn that sits on top of the cabinet. The two drivers share one amplifier channel. The design leans on three deliberate ideas:

Minimal passive parts
The woofer runs direct — no
series inductor, nothing in its
path. Only the compression driver carries a passive network (a second-order high-pass and a level-matching L-pad). Four components per speaker, total.

Efficiency first

### 96 dB woofer, 108 dB horn. The

whole system is happy on a handful of watts, so amplifier quality matters more than
amplifier power, and the horn's dynamics come for free.

DSP does the voicing
Baffle-step, the low-shelf lift, the

### 40 Hz excursion high-pass and

room correction all live in DSP — not in the crossover. The passive parts only set the acoustic crossover and match levels; tone is dialled after measurement.

The reference is the OJAS two-way (FaitalPRO 15″ + compression driver on a long tractrix); the Klipsch×OJAS kO-R2 crosses at 760 Hz with 97 dB sensitivity. The MP-H1 keeps that spirit but re-bases the drivers on parts stocked in Australia, and moves the tone controls into DSP.

02 | The drivers | DATASHEET VALUES

Woofer — Peerless by Tymphany FSL‑1225R02‑08 (8 Ω)
A pressed-steel pro 12″ on a paper cone and 65 mm voice coil, spec'd by Tymphany as “extremely flat to 3 kHz.” 96.2 dB sensitivity, Ø313.5 mm frame, ~96 mm deep.
FS | QTS | QES | VAS | RE | BL | SD | XMAX | MMS | LE | SENS. | POWER
63 Hz | 0.44 0.49 54.8 L | 5.5 Ω | 14.9 Tm | 547 cm² | 5.3 mm | 50.1 g | 0.54 mH | 96.2 dB | 233 W

Compression driver — SB Audience ROSSO‑65CD‑T (8 Ω)
108 dB (1 W / 1 m), 70 W AES / 140 W max,
Rdc 6.2 Ω
Range 500 Hz – 20 kHz; recommended
crossover 1 kHz
65 mm titanium diaphragm, ferrite motor, annular phase plug, copper-cap demodulation

1.4″ throat (35.6 mm exit), 18.4° conical Flange 4 × M6 on Ø102 mm PCD — the printed horn bolts straight on
Body Ø156 mm, 65.9 mm deep, 3.76 kg — carried by the printed stand, not the horn flange

Both drivers are stocked in Australia by Wagner Online (SB Audience / Peerless / Dayton distributor). They replaced the original Celestion pair, which went unobtainable locally — the cabinet and horn were designed to accept either without change.

MP-H1 · TWO-WAY HORN LOUDSPEAKER · BUI LD & DESIGN NOTES | TOM ANDREWS · OPEN BUI LD

03 | Cabinet & bass alignment | WHY 47 HZ

The enclosure is a 62 L net reflex box (456 × 536 × 366 mm external, 18 mm Baltic birch) with a full-width front slot port. Its tuning wasn't chosen as a target — it falls out of the box volume and the driver:

The alignment
α = Vas/Vb = 54.8 / 62 = 0.88
h = fb

/Fs = 0.76 → fb ≈ 0.76 × 63 = 48 Hz as-built 150 mm duct → ~47 Hz

Why not lower
The FSL's Qts of 0.44 is too high for a maximally-flat B4. A gentle QB3 alignment suits it — and 5.3 mm Xmax would run out of excursion long before 30 Hz. This is a high-sensitivity monitor, not a sub.

The result is a deliberately shallow roll-off. A DSP low-shelf (+3–4 dB below 100 Hz) plus normal room gain lifts the in-room response flat into the mid-40s.

FREQ (HZ) | 40 | 45 | 50 | 55 | 60 | 70 | 80 | 100 | 150 | 200
Response (dB) | −9.0 | −6.7 | −5.3 | −4.4 | −3.7 | −2.7 | −2.0 | −1.2 | −0.4 | −0.2

Extension & excursion
F3 = 67 Hz, F6 = 47 Hz, F10 = 38 Hz. Cone travel
is ~2.5 mm peak at 30 W across 48–200 Hz, well
inside the 5.3 mm Xmax

. Below fb

the cone unloads,
so a 40 Hz / 24 dB∕oct DSP high-pass protects it — essential once the low-shelf is in.

The port
A full-width slot at the base of the baffle: 420 × 28 mm (Sp = 117.6 cm²), 150 mm deep, formed by a shelf above the cabinet floor. Peak air velocity ~16.5 m/s at 30 W — just under the ~17 m/s chuffing threshold at ~112 dB peaks.
MP-H1 · TWO-WAY HORN LOUDSPEAKER · BUI LD & DESIGN NOTES | TOM ANDREWS · OPEN BUI LD

04 | The horn | TRACTRIX · 3D PRINTED

A round tractrix flare expands so the wavefront stays roughly spherical as it grows — smooth loading, minimal reflection back down the throat. The whole curve comes from one number, the flare cutoff fc

:

rₘ = c / (2π·fc) • x(r) = rₘ·ln((rₘ + √(rₘ²−r²)) / r) − √(rₘ²−r²)

The numbers
Throat Ø36 mm (fixed by the 1.4″ driver)
fc = 340 Hz → mouth Ø321 mm, length 303 mm
Loads effectively from ~450 Hz — over 1.5 octaves below the ~1.2 kHz crossover

### 6 mm walls throughout; the print must be dead

(a dull thock, not a ring)

Printed in sections
Too big for the bed, so it splits into one neck (with the driver bolt flange printed in) and four identical bell quadrants — a single STL rotated 90° four times. Every seam carries an integral tongue-andgroove printed into the parts: a continuous ring at the neck join, plus three tabs per quadrant seam. No hardware — dry-fit, epoxy in the grooves, tape, cure.

1.4″ throat · ∅36 mm

mouth ∅321 mm

axial length 303 mm

horn axis

Round tractrix profile — flare cutoff fc = 340 Hz. Plotted from the design equation.
The clever bit: tongue on the trailing face, groove on the leading face, so one quadrant self-tiles into a closed ring under rotation. Clearances (0.15 mm width / 0.2 mm depth) are tunable in the generator script for a tighter or looser printer.
MP-H1 · TWO-WAY HORN LOUDSPEAKER · BUI LD & DESIGN NOTES | TOM ANDREWS · OPEN BUI LD

05 | Crossover & wiring | FOUR PARTS, ONE CHANNEL

Both drivers hang on one amp channel. The woofer is wired direct; the compression driver gets a 2ndorder Butterworth high-pass then a level-matching L-pad.

negative rail — amp − · woofer − · both shunts · horn −

AMP
+ in

12″ WOOFER

direct — no filter in the woofer path

C

12 µF

A

L
1.5 mH

R1 6.8Ω

B

R2
2.7Ω

1.4″ CD + HORN

Signal path, one amp channel. Woofer taps the input directly; the CD chain is C+L (high-pass) then R1/R2 (L-pad).

High-pass — the crossover
12 µF series + 1.5 mH shunt gives fc = 1.19 kHz,
Q ≈ 0.72 — a clean second-order Butterworth,
safely above the ROSSO's 1 kHz minimum. The woofer needs no low-pass: its own roll-off plus the horn's takeover cover the handover.

L-pad — the level match
The 108 dB horn is dropped ~12 dB to meet the 96 dB woofer: series 6.8 Ω / shunt 2.7 Ω (10 W wirewound). It also keeps the CD seeing a steady ~8 Ω, which damps the horn's impedance peaks so the crossover stays put. Final trim is by ear / REW.

System impedance dips to ~4.4 Ω near crossover — safe on any 4 Ω-rated channel. Terminals are four binding posts: rear pair = amp in, top pair feeds the external horn up through the lid. Start with the compression driver inverted and confirm the summed response in REW.

MP-H1 · TWO-WAY HORN LOUDSPEAKER · BUI LD & DESIGN NOTES | TOM ANDREWS · OPEN BUI LD

06 | Voicing with DSP | MEASURE, THEN CORRECT

The passive network sets the crossover and matches levels; everything tonal is DSP. A calibrated mic (UMIK-1) and REW turn the raw speaker into a voiced one in an afternoon. Enter these baseline blocks first — they're design maths, not taste:

DSP BLOCK | SETTING | WHY
High-pass | 40 Hz, 24 dB∕oct | protects the woofer below fb where the box unloads the cone
Low-shelf | +3 dB <100 Hz, Q 0.7 | fills the shallow QB3 roll-off / baffle step
Peak (placeholder) | −2 dB @ 1.6 kHz, Q 2 | typical woofer/horn overlap bump; refine by measurement

Measurement pass
Nearfield: confirm the port peaks ~47 Hz —
verifies box tuning before any EQ.
CD polarity: flip the horn leads, keep whichever sums smoothly through 1–1.5 kHz.
Level match: horn band vs woofer band; if >±1.5 dB, change the L-pad series resistor, don't burn DSP headroom.

Room & target
Multi-position sweep at the seat; correct room modes below 500 Hz freely.
Above 500 Hz, only broad trends (Q ≤ 2, cuts preferred) — never fill narrow dips.
Target: flat 200 Hz–2 kHz, then a gentle downward tilt (~−4 dB by 10 kHz). Trust your ears for the last dB.

This build uses a NAD C 700 with Dirac Live — chosen for impulse-response correction, because the horn's acoustic centre sits well behind the woofer's and that arrival-time error can't be fixed by magnitude EQ alone. Start with the limited-bandwidth licence (corrects to ~500 Hz — enough for room modes and the baffle step).

MP-H1 · TWO-WAY HORN LOUDSPEAKER · BUI LD & DESIGN NOTES | TOM ANDREWS · OPEN BUI LD

07 | Bill of materials | PER PAIR · EST. AUD
GROUP | KEY ITEMS | EST. AUD
Drivers | 2× FSL-1225 12″ woofer, 2× ROSSO-65CD-T compression driver | 850–1,000
Crossover | 2× 12 µF MKP cap, 2× 1.5 mH air-core coil, 4× wirewound resistor | ~100
Timber & hardware | 18 mm Baltic birch, feet, binding posts, T-nuts, wadding, wire | ~440
Horn & finish | ~5 kg PETG, stand hardware, filler, primer, topcoat | ~255
Total | excludes the measurement mic (~$150 if not owned) | 1,650–1,850

Prices checked mid-2026; small-run pro-audio stock moves — confirm at order time. Most of the electronics ship in one box from a single distributor; plywood and timber are the only local buys.

08 | Field notes | WHAT THE BUILD TAUGHT US

The one that nearly fooled us — check polarity first
First power-up: the bass was gone — thin and lifeless. The tempting move is to blame the port tuning or the crossover. Instead: an AA battery across each woofer's terminals, watching the cones. One punched out, the other pulled in — one woofer was wired out of phase, and the two were cancelling each other acoustically in the room. Two minutes to fix. They went from lifeless to alive. Battery-test your polarity before you second-guess the acoustics.

Cut the woofer hole to the driver's real
cutout, not the frame OD — the flange must
land on solid baffle. Cut slightly small, open out
on a test-fit.
Seal everything. A reflex box that leaks loses bass — bed the top posts and gasket the woofer.

Register your printed seams. The quadrant-toquadrant joints, not the neck join, are where misalignment shows — give them positive location.
Leave the L-pad resistors swappable (long leads / a lever-nut) — you re-trim by ear once you measure this horn.

Designed & built by Tom Andrews on the Mornington Peninsula. Acoustic maths from box_model.py / tractrix.py; horn generated headless in build123d. Round tractrix, single-amp, high-sensitivity two-way.

N E X T RE V ISI O N
MP-H2
elliptical R-OSSE waveguide
MP-H1 · TWO-WAY HORN LOUDSPEAKER · BUI LD & DESIGN NOTES | TOM ANDREWS · OPEN BUI LD
